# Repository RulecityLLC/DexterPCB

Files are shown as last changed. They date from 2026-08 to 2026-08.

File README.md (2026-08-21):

# DexterPCB
Contains all files needed to create/modify the Dexter custom PCB.

Dexter is a hardware replacement for laserdisc players used in arcade games such as Dragon's Lair.

Dexter is a two board solution: a larger custom PCB that sits on the bottom and a smaller Raspberry Pi v2 the sits on the top.  This repo contains the Eagle files and Bill of Materials spreadsheet to create/modify the custom PCB that sits on the bottom.

The Dexter custom PCB contains two microcontrollers.  The source code for these microcontroller is at https://github.com/RulecityLLC/DexterFirmware .

# PCB
I created this PCB with Eagle v6.  It should work with KiCad's EAGLE importer though I have not tested it.

# Bill of Materials
I included the actual spreadsheet I use when ordering parts for this PCB and assembling this PCB.

# Support
If you need help having PCBs made from the source files or with any other aspect of this repository, I offer commercial support: https://www.daphne-emu.com:9443/mediawiki/index.php/CommercialSupport

--Matt Ownby

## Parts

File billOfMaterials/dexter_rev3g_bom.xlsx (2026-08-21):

Quantity | Reference | Package | Manufacturer | Mfg # | Distributor | Dist # | Note | Best Price
SURFACE MOUNT
22 | C1-C4,C7-C10,C12-C13,C16-C24,C25-C27 | 1206 | Samsung | CL31B104JBCNNNC | Digi-Key | 1276-1165-1-ND | 0.1uF
4 | C5,C6,C14-C15 | 1206 | Kemet | C1206C200J5GACTU | Digi-Key | 399-1196-1-ND | 20pF (for both 16 MHz and 18.432 MHz crystals)
1 | IC1 | TQFP44 | Atmel | ATMEGA644PA-AU | Digi-Key | ATMEGA644PA-AU-ND | microcontroller
2 | IC2,IC4 | SO18 | Maxim | MAX222CWN+ | Digi-Key | MAX222CWN+-ND | serial drivers
1 | IC3 | 8-SOIC | TI | LM1881MX/NOPB | Digi-Key | LM1881MX/NOPBCT-ND | video sync separator (Digikey says discontinued!)
1 | IC5 | TSSOP24 | STP | STP16CP05TTR | Digi-Key | 497-5744-1-ND | LED driver
1 | IC6 | TSSOP20 | Texas Instruments | SN74LS244DBR | Digi-Key | 296-26509-1-ND | octal tri-state buffer
1 | IC7 | TSSOP5 | NXP | 74AHCT1G32GW,125 | Digi-Key | 568-4464-1-ND | OR gate 2-input. TI alternative: 296-4713-1-ND | newark for TI alternate
1 | IC8 | 4-SOP | IXYS Integrated Circuits Division | CPC1008NTR | Digi-Key | CLA216CT-ND | Solid state relay
1 | IC9 | TSSOP24 | Texas Instruments | SN74CBTD3384PWR | Digi-Key | 296-1173-1-ND | 5V <-> 3.3V I/O
1 | IC10 | TSSOP6 | Texas Instruments | SN74LVC1G332DCKR | Digi-Key | 296-15943-1-ND | 3-input OR gate (high level is > 3.5V which is ok since AVR is sourcing all inputs)
1 | IC11 | TSSOP14 | Diodes Inc. | 74HCT126T14-13 | Digi-Key | 74HCT126T14-13DICT-ND | tri-state buffer
14 | LED2,LED3,LED6,LED7,LED8,LED10,LED11,LED13,LED14,LED15,LED16,LED17,LED18,LED19 | 1206 | Kingbright Company LLC | APT3216SGC | Digi-Key | 754-1141-1-ND | All LEDs
3 | R1,R23,R25 | 1206 | Panasonic | ERJ-8ENF6803V | Digi-Key | P680KFCT-ND | R680k
2 | R2,R22 | 1206 | Panasonic | ERJ-8ENF3300V | Digi-Key | P330FCT-ND | R330
5 | R3,R7,R14,R19,R21 | 1206 | Panasonic | ERJ-8ENF1501V | Digi-Key | P1.50KFCT-ND | R1500
7 | R4,R5,R10,R11,R13,R16,R24 | 1206 | Panasonic | ERJ-8ENF1001V | Digi-Key | P1.00KFCT-ND | R1k
3 | R6,R9,R15 | 1206 | Panasonic | ERJ-8ENF75R0V | Digi-Key | P75.0FCT-ND | R75
4 | R8,R12,R26,R27 | 1206 | Panasonic | ERJ-8ENF4701V | Digi-Key | P4.70KFCT-ND | R4.7k
3 | R17,R18,R20 | 1206 | Panasonic | ERJ-8ENF7500V | Digi-Key | P750FCT-ND | R750
1 | U1 | UMAX (SMD) | Maxim | MAX4313EUA+ | Digi-Key | MAX4313EUA+-ND | video MUX
1 | U2 | TQFP32 | Atmel | ATMEGA328P-AU | Digi-Key | ATMEGA328P-AU-ND | ATMEGA328P
1 | Y1 | CRYSTAL-CSM-3X (SMD) | ECS Inc | ECS-184-20-3X-TR | Digi-Key | XC1777CT-ND | 18.432 MHz
1 | Y2 | CRYSTAL-CSM-3X (SMD) | ECS Inc | ECS-160-20-3X-TR | Digi-Key | XC1776CT-ND | 16 MHz
2 | Z1,Z2 | SOT-23 (SMD) | Micro Commercial Co | BAT54S-TP | Digi-Key | BAT54STPMSCT-ND | BAT54S
THROUGH-HOLE
3 | S2-S4 | TACTILE-PTH | Omron | B3F-1020 | Digi-Key | SW402-ND | push button
1 | X1 | DB25 (PTH) | TE Connectivity | 5745783-4 | Digi-Key | A32077-ND | DB25 | Mouser/Newark ($3.22/ea for 100+)
1 | X2 | CENTRONICS24 (PTH) | Norcomp Inc | 112-024-213R001 | Digi-Key | 1024RFA-ND | CENTRONICS 24 (warning, stock is low, we may need to find different supplier) | DO NOT INSTALL FASTENER THINGIES, Star Rider connector isn't compatible with them
1 | JP7 | 2x13 (PTH) | TE Connectivity | 5103308-6 | Digi-Key | A33167-ND | Raspberry Pi header
2 | JP16,JP17 | 1X2 (keyed, PTH) | Molex | 22232021 | Digi-Key | WM4200-ND | 1x2 keyed header (5V/GND)
1 | IR1 | VISHAY | Vishay | TSOP2438 | Digi-Key | TSOP2438-ND | Infrared receiver (see also TSOP32438-ND which looks to be compatible and newer)
2 | J1,J8 | 2X3 (PTH) | Molex | 901310123 | Digi-Key | WM8121-ND | 2x3 pin header for ISP program
1 | J2 | POWER_JACK_PTH | CUI | PJ-002A | Digi-Key | CP-002A-ND | power jack
1 | J3 | BNCPTH | TE Connectivity | 1-1478031-0 | Digi-Key | ACX1971-ND | 75 ohm BNC connector (A97559-ND is older obsolete part)
1 | J5 | 3.5mm stereo with tip | CUI | SJ1-3554NG | Digi-Key | CP1-3554NG-ND | 3.5mm stereo jack with tip switch (PR-8210 jack) [alternate part CP1-3544N-ND]
1 | J4 | 3.5mm 4 terminals (PTH) | CUI | SJ-43514 | Digi-Key | CP-43514-ND | 3.5mm A/V jack (4 terminals) [digikey was out of stock for these but then got 20k in so be careful]
1 | C11 | CPOL-RADIAL (PTH) | Panasonic | EEU-FC1A471 | Digi-Key | P10221-ND | 470uF/10V (alt UPW1A471MPD)
1 | F1 | PTCPTH | Littelfuse, Inc | 72R025XU | Digi-Key | F3193-ND | Resettable fuse PTC. 250mA Newer replacement: RXEF025HF-ND
1 | AUD_LEFT | RCA-SWITCHCRAFT-4X (PTH) | Switchcraft | PJRAN1X1U01X | Digi-Key | PJRAN1X1U01X-ND | RCA port (black)
1 | AUD_RIGHT | RCA-SWITCHCRAFT-4X (PTH) | Switchcraft | PJRAN1X1U03X | Digi-Key | PJRAN1X1U03X-ND | RCA port (red)

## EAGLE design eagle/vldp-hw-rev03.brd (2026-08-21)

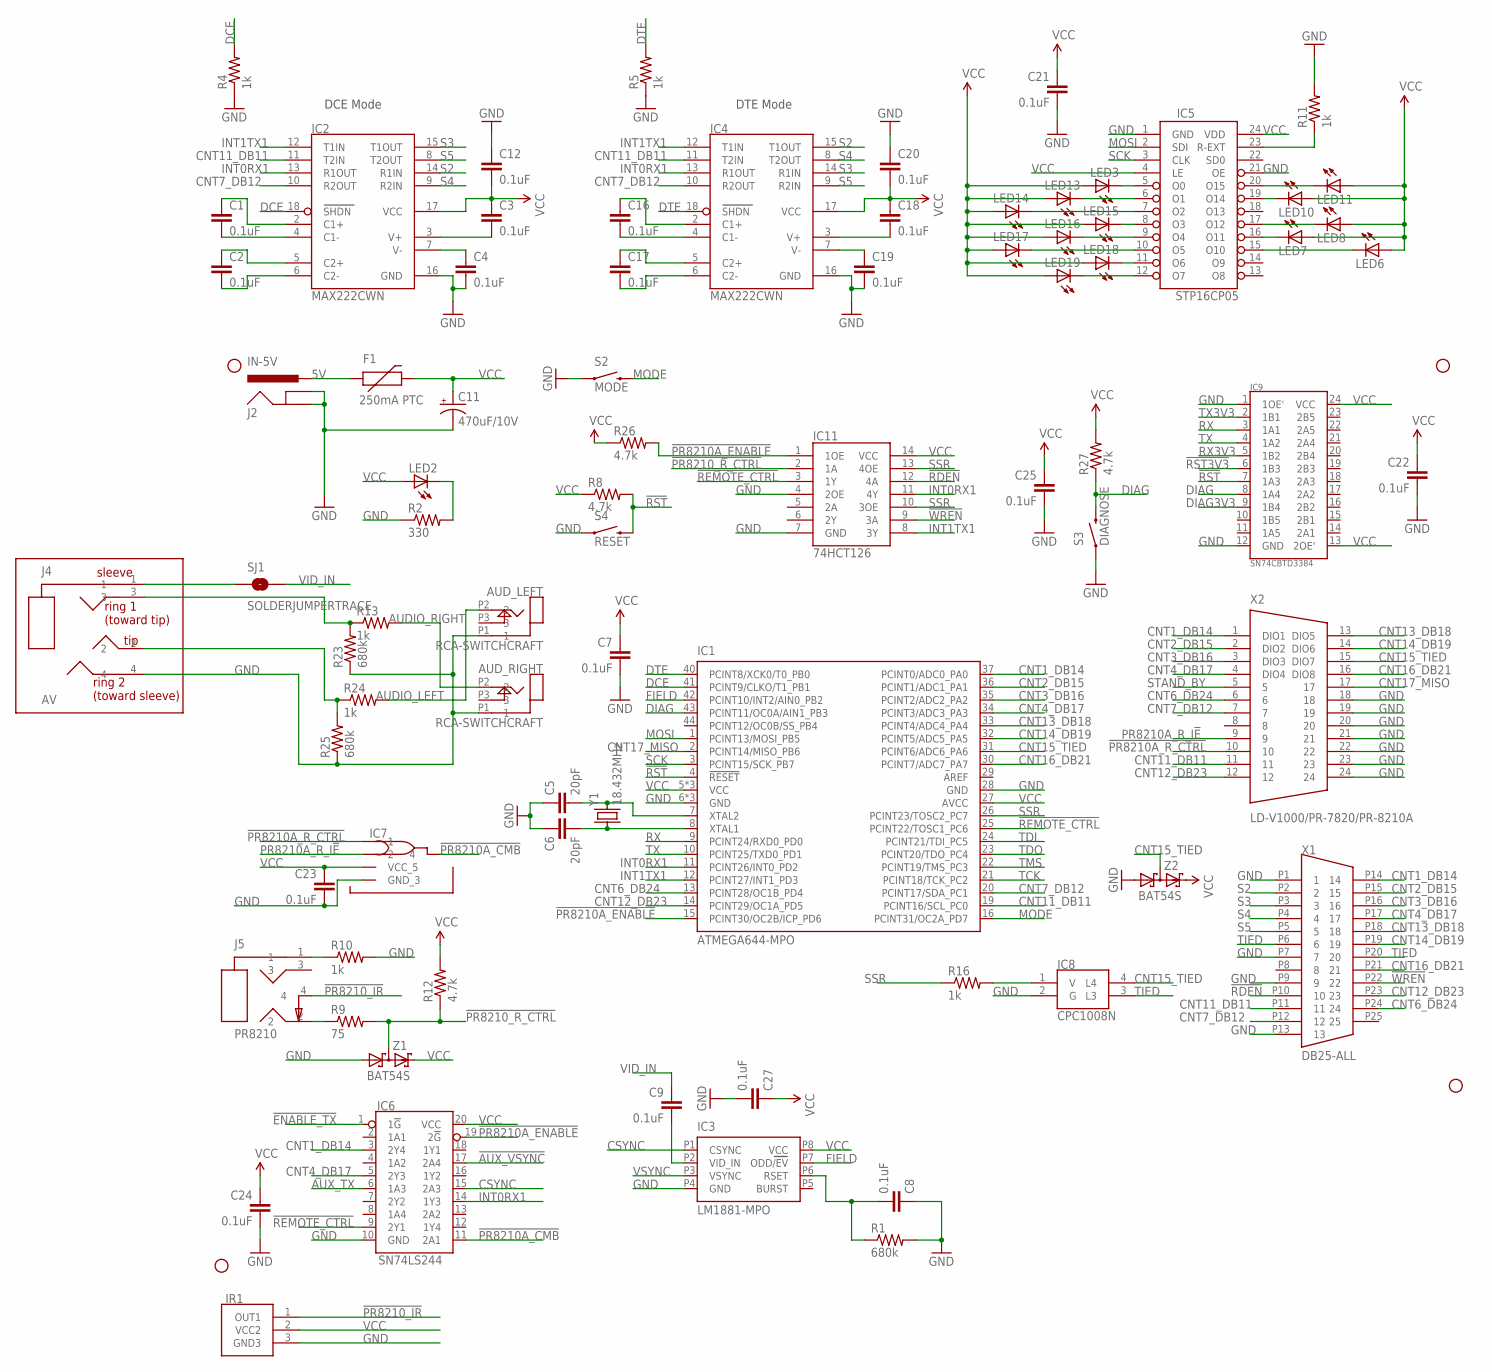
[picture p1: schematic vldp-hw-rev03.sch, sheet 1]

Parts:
AUD_LEFT: RCA-SWITCHCRAFT; RCA-SWITCHCRAFT-4X
AUD_RIGHT: RCA-SWITCHCRAFT; RCA-SWITCHCRAFT-4X
C1, C2, C3, C4, C7, C8, C9, C12, C16, C17, C18, C19, C20, C21, C22, C23, C24, C25, C27: 0.1uF; 1206
C5, C6: 20pF; 1206
C11: 470uF/10V; CPOL-RADIAL-10UF-25V
F1: 250mA PTC; PTC
IC1: ATMEGA644-MPO; TQFP44
IC2, IC4: MAX222CWN; SO18
IC3: LM1881-MPO; LM1881M
IC5: STP16CP05; TSSOP24
IC6: SN74LS244; TSSOP20-MPO
IC7: PR8210A_RMT; TSSOP5
IC8: CPC1008N
IC9: SN74CBTD3384; TSSOP24
IC11: 74HCT126; TSSOP14-MPO
IR1: TSOP2438; VISHAY
J2: IN-5V; POWER_JACK_PTH
J4: AV; 3.5MM-SJ-43514
J5: PR8210; 3.5MM-SJ1-3554NG
JP1, JP2, JP3, JP4: STAND-OFF
LED2, LED3, LED6, LED7, LED8, LED10, LED11, LED13, LED14, LED15, LED16, LED17, LED18, LED19: LED1206; LED-1206
R1, R23, R25: 680k; 1206
R2: 330; 1206
R4, R5, R10, R11, R13, R16, R24: 1k; 1206
R8, R12, R26, R27: 4.7k; 1206
R9: 75; 1206
S2: MODE; TACTILE-PTH
S3: DIAGNOSE; TACTILE-PTH
S4: RESET; TACTILE-PTH
SJ1: SOLDERJUMPERTRACE; SJ_2S-TRACE
X1: DB25-ALL; A32077-ND
X2: LD-V1000/PR-7820/PR-8210A; 112-YYY-213R001
Y1: 18.432MHz; CRYSTAL-CSM-3X
Z1, Z2: BAT54S; SOT23

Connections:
5V: F1.P$1 (1), J2.PWR; also elsewhere on the board
!AUX_VSYNC: IC6.17 (2A4); also elsewhere on the board
!ENABLE_TX: IC6.1 (1!G); also elsewhere on the board
!PR8210A_CMB: IC6.11 (2A1), IC7.P$4 (4)
!PR8210A_ENABLE: IC1.15 (PCINT30/OC2B/ICP_PD6), IC6.19 (2!G), IC11.1 (1OE), R26.2
!PR8210A_R_CTRL: IC7.P$1 (1), X2.10
!PR8210_IR: IR1.1 (OUT1), J5.4
!PR8210_R_CTRL: IC11.2 (1A), R9.2, R12.1, Z1.3 (C1A2)
!RDEN: IC11.12 (4A), X1.P10 (10)
!REMOTE_CTRL: IC1.25 (PCINT22/TOSC1_PC6), IC6.9 (2Y1), IC11.3 (1Y)
!RST: IC1.4 (!RESET), IC9.7 (1A3), R8.2, S4.3 (2); also elsewhere on the board
!RST3V3: IC9.6 (1B3); also elsewhere on the board
!WREN: IC11.9 (3A), X1.P22 (22)
AUDIO_LEFT: AUD_LEFT.P2 (2), R24.2; also elsewhere on the board
AUDIO_RIGHT: AUD_RIGHT.P2 (2), R13.2; also elsewhere on the board
AUX_TX: IC6.6 (1A3); also elsewhere on the board
CNT1_DB14: IC1.37 (PCINT0/ADC0_PA0), IC6.3 (2Y4), X1.P14 (14), X2.1 (DIO1)
CNT2_DB15: IC1.36 (PCINT1/ADC1_PA1), X1.P15 (15), X2.2 (DIO2)
CNT3_DB16: IC1.35 (PCINT2/ADC2_PA2), X1.P16 (16), X2.3 (DIO3)
CNT4_DB17: IC1.34 (PCINT3/ADC3_PA3), IC6.5 (2Y3), X1.P17 (17), X2.4 (DIO4)
CNT6_DB24: IC1.13 (PCINT28/OC1B_PD4), X1.P24 (24), X2.6; also elsewhere on the board
CNT7_DB12: IC1.20 (PCINT17/SDA_PC1), IC2.10 (R2OUT), IC4.10 (R2OUT), X1.P12 (12), X2.7
CNT11_DB11: IC1.19 (PCINT16/SCL_PC0), IC2.11 (T2IN), IC4.11 (T2IN), X1.P11 (11), X2.11; also elsewhere on the board
CNT12_DB23: IC1.14 (PCINT29/OC1A_PD5), X1.P23 (23), X2.12; also elsewhere on the board
CNT13_DB18: IC1.33 (PCINT4/ADC4_PA4), X1.P18 (18), X2.13 (DIO5)
CNT14_DB19: IC1.32 (PCINT5/ADC5_PA5), X1.P19 (19), X2.14 (DIO6)
CNT15_TIED: IC1.31 (PCINT6/ADC6_PA6), IC8.4 (L4), X2.15 (DIO7), Z2.3 (C1A2)
CNT16_DB21: IC1.30 (PCINT7/ADC7_PA7), X1.P21 (21), X2.16 (DIO8)
CNT17_MISO: IC1.2 (PCINT14/MISO_PB6), X2.17; also elsewhere on the board
CSYNC: IC3.P1 (CSYNC), IC6.15 (2A3); also elsewhere on the board
DCE: IC1.41 (PCINT9/CLKO/T1_PB1), IC2.18 (SHDN), R4.2; also elsewhere on the board
DIAG: IC1.43 (PCINT11/OC0A/AIN1_PB3), IC9.8 (1A4), R27.1, S3.3 (2); also elsewhere on the board
DIAG3V3: IC9.9 (1B4); also elsewhere on the board
DTE: IC1.40 (PCINT8/XCK0/T0_PB0), IC4.18 (SHDN), R5.2; also elsewhere on the board
FIELD: IC1.42 (PCINT10/INT2/AIN0_PB2), IC3.P7 (ODD/EV); also elsewhere on the board
GND: AUD_LEFT.P1 (1), AUD_RIGHT.P1 (1), C4.2, C5.1, C6.1, C7.2, C8.1, C11.2 (-), C12.1, C19.2, C20.1, C21.2, C22.2, C23.2, C24.2, C25.2, C27.2, IC1.6 (GND), IC1.18 (GND), IC1.28 (GND), IC1.39 (GND), IC2.16 (GND), IC3.P4 (GND), IC4.16 (GND), IC5.1 (GND), IC5.21 (OE), IC6.10 (GND), IC7.P$3 (GND_3), IC8.2 (G), IC9.1 (1OE'), IC9.12 (GND), IC11.4 (2OE), IC11.7 (GND), IR1.3 (GND3), J2.GND, J2.GNDBREAK, J4.4, R1.2, R2.1, R4.1, R5.1, R10.2, R11.2, R23.1, R25.1, S2.1, S3.1, S4.1, X1.P1 (1), X1.P7 (7), X1.P9 (9), X1.P13 (13), X2.18, X2.19, X2.20, X2.21, X2.22, X2.23, X2.24, Z1.1 (A1), Z2.1 (A1); also elsewhere on the board
INT0RX1: IC1.11 (PCINT26/INT0_PD2), IC2.13 (R1OUT), IC4.13 (R1OUT), IC6.14 (1Y3), IC11.11 (4Y); also elsewhere on the board
INT1TX1: IC1.12 (PCINT27/INT1_PD3), IC2.12 (T1IN), IC4.12 (T1IN), IC11.8 (3Y); also elsewhere on the board
MODE: IC1.16 (PCINT31/OC2A_PD7), S2.3 (2)
MOSI: IC1.1 (PCINT13/MOSI_PB5), IC5.2 (SDI); also elsewhere on the board
unnamed: C2.1, IC2.5 (C2+)
unnamed: C5.2, IC1.7 (XTAL2), Y1.P$2
unnamed: C6.2, IC1.8 (XTAL1), Y1.P$1
unnamed: C1.2, IC2.4 (C1-)
unnamed: C1.1, IC2.2 (C1+)
unnamed: IC8.1 (V), R16.2
unnamed: C2.2, IC2.6 (C2-)
unnamed: C16.2, IC4.4 (C1-)
unnamed: J5.1, R10.1
unnamed: C8.2, IC3.P6 (RSET), R1.1
unnamed: C9.2, IC3.P2 (VID_IN)
unnamed: LED2.C, R2.2
unnamed: J4.1, SJ1.1
unnamed: J4.2, R24.1, R25.2
unnamed: IC5.5 (O0), LED3.C
unnamed: IC5.6 (O1), LED13.C
unnamed: IC5.7 (O2), LED14.C
unnamed: IC5.8 (O3), LED15.C
unnamed: C16.1, IC4.2 (C1+)
unnamed: C17.1, IC4.5 (C2+)
unnamed: C17.2, IC4.6 (C2-)
unnamed: IC5.9 (O4), LED16.C
unnamed: IC5.10 (O5), LED17.C
unnamed: IC5.11 (O6), LED18.C
unnamed: IC5.12 (O7), LED19.C
unnamed: J4.3, R13.1, R23.2
unnamed: IC5.15 (O10), LED6.C
unnamed: IC5.16 (O11), LED7.C
unnamed: IC5.17 (O12), LED8.C
unnamed: IC5.19 (O14), LED10.C
unnamed: IC5.20 (O15), LED11.C
unnamed: IC5.23 (R-EXT), R11.1
PR8210A_R_I!E: IC7.P$2 (2), X2.9
PR8210_TIP: J5.2, R9.1
RX: IC1.9 (PCINT24/RXD0_PD0), IC9.3 (1A1); also elsewhere on the board
RX3V3: IC9.5 (1B2); also elsewhere on the board
S2: IC2.14 (R1IN), IC4.15 (T1OUT), X1.P2 (2)
S3: IC2.15 (T1OUT), IC4.14 (R1IN), X1.P3 (3)
S4: IC2.9 (R2IN), IC4.8 (T2OUT), X1.P4 (4)
S5: IC2.8 (T2OUT), IC4.9 (R2IN), X1.P5 (5)
SCK: IC1.3 (PCINT15/SCK_PB7), IC5.3 (CLK); also elsewhere on the board
SSR: IC1.26 (PCINT23/TOSC2_PC7), IC11.10 (3OE), IC11.13 (4OE), R16.1; also elsewhere on the board
STAND_BY: X2.5; also elsewhere on the board
TCK: IC1.21 (PCINT18/TCK_PC2); also elsewhere on the board
TDI: IC1.24 (PCINT21/TDI_PC5); also elsewhere on the board
TDO: IC1.23 (PCINT20/TDO_PC4); also elsewhere on the board
TIED: IC8.3 (L3), X1.P6 (6), X1.P20 (20)
TMS: IC1.22 (PCINT19/TMS_PC3); also elsewhere on the board
TX: IC1.10 (PCINT25/TXD0_PD1), IC9.4 (1A2); also elsewhere on the board
TX3V3: IC9.2 (1B1); also elsewhere on the board
V+1: C3.2, IC2.3 (V+)
V+2: C18.2, IC4.3 (V+)
V-1: C4.1, IC2.7 (V-)
V-2: C19.1, IC4.7 (V-)
VCC: C3.1, C7.1, C11.1 (+), C12.2, C18.1, C20.2, C21.1, C22.1, C23.1, C24.1, C25.1, C27.1, F1.P$2 (2), IC1.5 (VCC), IC1.17 (VCC), IC1.27 (AVCC), IC1.38 (VCC), IC2.17 (VCC), IC3.P8 (VCC), IC4.17 (VCC), IC5.4 (LE), IC5.24 (VDD), IC6.20 (VCC), IC7.P$5 (VCC_5), IC9.13 (2OE'), IC9.24 (VCC), IC11.14 (VCC), IR1.2 (VCC2), LED2.A, LED3.A, LED6.A, LED7.A, LED8.A, LED10.A, LED11.A, LED13.A, LED14.A, LED15.A, LED16.A, LED17.A, LED18.A, LED19.A, R8.1, R12.2, R26.1, R27.2, Z1.2 (C2), Z2.2 (C2); also elsewhere on the board
VID_IN: C9.1, SJ1.2; also elsewhere on the board
VSYNC: IC3.P3 (VSYNC); also elsewhere on the board

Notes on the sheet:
DCE Mode
DTE Mode

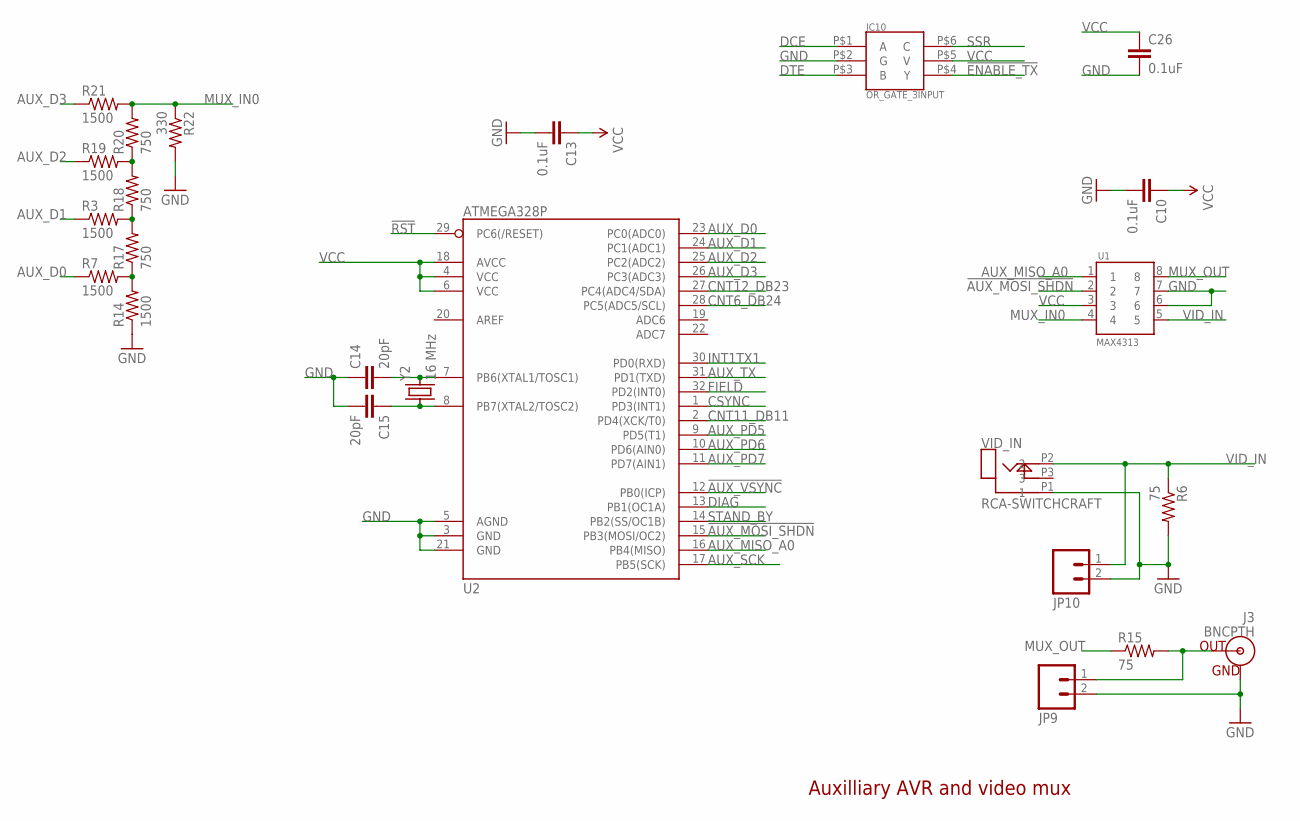
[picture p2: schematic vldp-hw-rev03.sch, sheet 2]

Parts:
C10, C13, C26: 0.1uF; 1206
C14, C15: 20pF; 1206
IC10: OR_GATE_3INPUT; TSSOP6-DCK
J3: BNCPTH; BNC
JP9, JP10: M02PTH; 1X02
R3, R7, R14, R19, R21: 1500; 1206
R6, R15: 75; 1206
R17, R18, R20: 750; 1206
R22: 330; 1206
U1: MAX4313; MAXIM-UMAX-LONGPADS
U2: ATMEGA328P; TQFP32-LONGPADS
VID_IN: RCA-SWITCHCRAFT; RCA-SWITCHCRAFT-4X
Y2: 16 MHz; CRYSTAL-CSM-3X

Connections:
!AUX_MOSI_SHDN: U1.2, U2.15 (PB3(MOSI/OC2)); also elsewhere on the board
!AUX_VSYNC: U2.12 (PB0(ICP)); also elsewhere on the board
!ENABLE_TX: IC10.P$4 (Y); also elsewhere on the board
!RST: U2.29 (PC6(/RESET)); also elsewhere on the board
AUX_D0: R7.1, U2.23 (PC0(ADC0))
AUX_D1: R3.1, U2.24 (PC1(ADC1))
AUX_D2: R19.1, U2.25 (PC2(ADC2))
AUX_D3: R21.1, U2.26 (PC3(ADC3))
AUX_MISO_A0: U1.1, U2.16 (PB4(MISO)); also elsewhere on the board
AUX_PD5: U2.9 (PD5(T1)); also elsewhere on the board
AUX_PD6: U2.10 (PD6(AIN0)); also elsewhere on the board
AUX_PD7: U2.11 (PD7(AIN1)); also elsewhere on the board
AUX_SCK: U2.17 (PB5(SCK)); also elsewhere on the board
AUX_TX: U2.31 (PD1(TXD)); also elsewhere on the board
CNT6_DB24: U2.28 (PC5(ADC5/SCL)); also elsewhere on the board
CNT11_DB11: U2.2 (PD4(XCK/T0)); also elsewhere on the board
CNT12_DB23: U2.27 (PC4(ADC4/SDA)); also elsewhere on the board
CSYNC: U2.1 (PD3(INT1)); also elsewhere on the board
DCE: IC10.P$1 (A); also elsewhere on the board
DIAG: U2.13 (PB1(OC1A)); also elsewhere on the board
DTE: IC10.P$3 (B); also elsewhere on the board
FIELD: U2.32 (PD2(INT0)); also elsewhere on the board
GND: C10.2, C13.2, C14.1, C15.2, C26.2, IC10.P$2 (G), J3.GND, JP9.2, JP10.2, R6.2, R14.1, R22.2, U1.6, U1.7, U2.3 (GND), U2.5 (AGND), U2.21 (GND), VID_IN.P1 (1); also elsewhere on the board
INT1TX1: U2.30 (PD0(RXD)); also elsewhere on the board
MUX_IN0: R20.2, R21.2, R22.1, U1.4
MUX_OUT: R15.1, U1.8
unnamed: J3.S (OUT), JP9.1, R15.2
unnamed: R3.2, R17.2, R18.1
unnamed: R7.2, R14.2, R17.1
unnamed: R18.2, R19.2, R20.1
unnamed: C14.2, U2.7 (PB6(XTAL1/TOSC1)), Y2.P$2
unnamed: C15.1, U2.8 (PB7(XTAL2/TOSC2)), Y2.P$1
SSR: IC10.P$6 (C); also elsewhere on the board
STAND_BY: U2.14 (PB2(SS/OC1B)); also elsewhere on the board
VCC: C10.1, C13.1, C26.1, IC10.P$5 (V), U1.3, U2.4 (VCC), U2.6 (VCC), U2.18 (AVCC); also elsewhere on the board
VID_IN: JP10.1, R6.1, U1.5, VID_IN.P2 (2); also elsewhere on the board

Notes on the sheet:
Auxilliary AVR and video mux

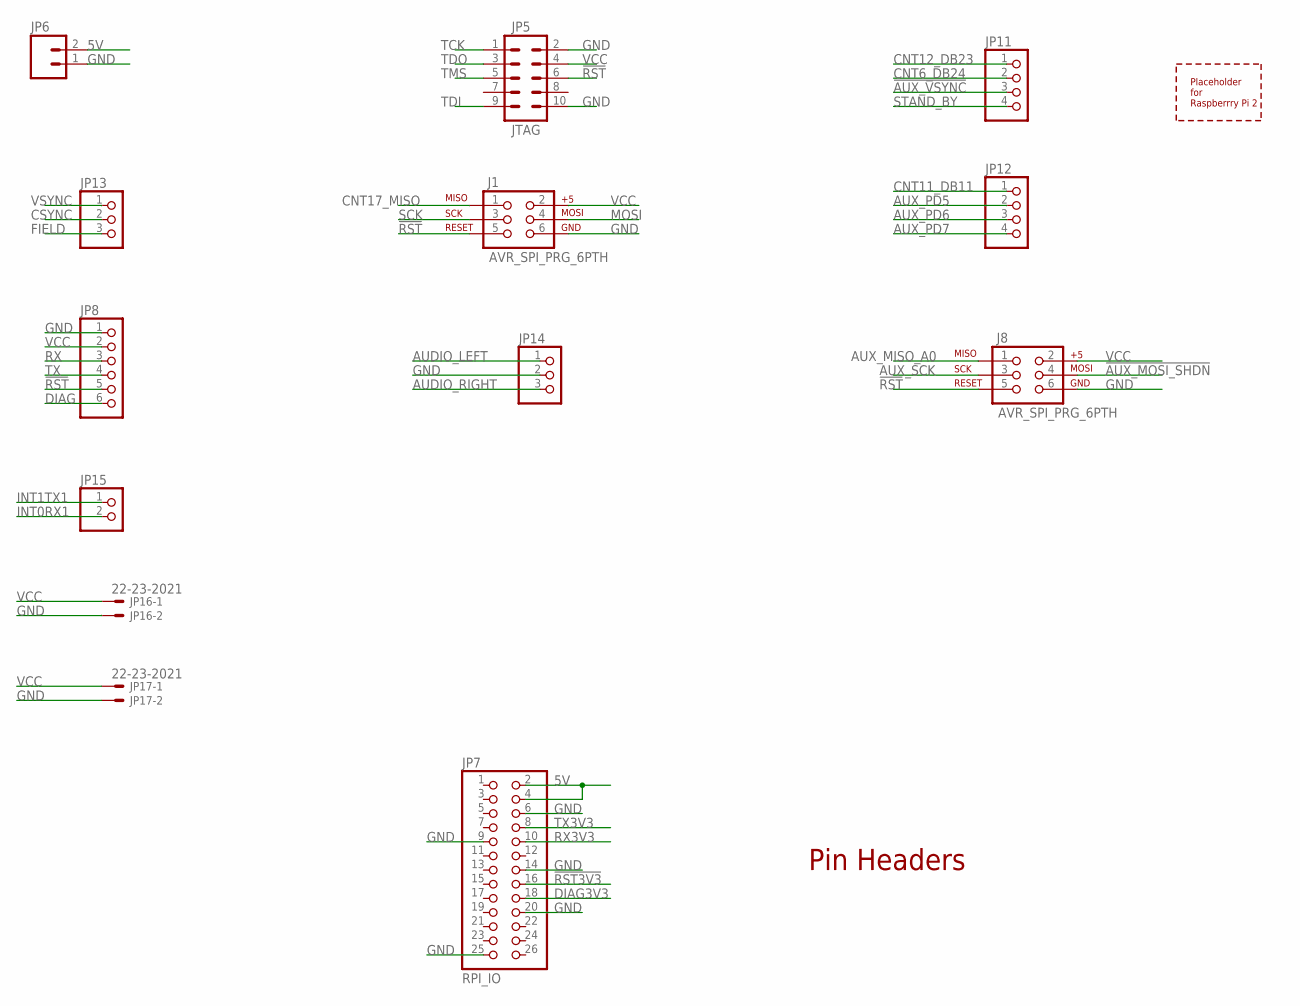
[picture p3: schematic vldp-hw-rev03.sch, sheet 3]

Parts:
J1, J8: AVR_SPI_PRG_6PTH; 2X3
JP5: JTAG; AVR_ICSP
JP6: M02PTH; 1X02
JP7: RPI_IO; 2X13
JP8: PINHD-1X6; 1X06
JP11, JP12: PINHD-1X4; 1X04
JP13, JP14: PINHD-1X3; 1X03
JP15: PINHD-1X2; 1X02
JP16, JP17: 22-23-2021
U$1: RASPBERRY_PI2_LAYOUT; RPI2

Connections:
5V: JP6.2, JP7.2, JP7.4; also elsewhere on the board
!AUX_MOSI_SHDN: J8.4; also elsewhere on the board
!AUX_VSYNC: JP11.3; also elsewhere on the board
!RST: J1.5, J8.5, JP5.6, JP8.5; also elsewhere on the board
!RST3V3: JP7.16; also elsewhere on the board
AUDIO_LEFT: JP14.1; also elsewhere on the board
AUDIO_RIGHT: JP14.3; also elsewhere on the board
AUX_MISO_A0: J8.1; also elsewhere on the board
AUX_PD5: JP12.2; also elsewhere on the board
AUX_PD6: JP12.3; also elsewhere on the board
AUX_PD7: JP12.4; also elsewhere on the board
AUX_SCK: J8.3; also elsewhere on the board
CNT6_DB24: JP11.2; also elsewhere on the board
CNT11_DB11: JP12.1; also elsewhere on the board
CNT12_DB23: JP11.1; also elsewhere on the board
CNT17_MISO: J1.1; also elsewhere on the board
CSYNC: JP13.2; also elsewhere on the board
DIAG: JP8.6; also elsewhere on the board
DIAG3V3: JP7.18; also elsewhere on the board
FIELD: JP13.3; also elsewhere on the board
GND: J1.6, J8.6, JP5.2, JP5.10, JP6.1, JP7.6, JP7.9, JP7.14, JP7.20, JP7.25, JP8.1, JP14.2, JP16.2, JP17.2; also elsewhere on the board
INT0RX1: JP15.2; also elsewhere on the board
INT1TX1: JP15.1; also elsewhere on the board
MOSI: J1.4; also elsewhere on the board
RX: JP8.3; also elsewhere on the board
RX3V3: JP7.10; also elsewhere on the board
SCK: J1.3; also elsewhere on the board
STAND_BY: JP11.4; also elsewhere on the board
TCK: JP5.1; also elsewhere on the board
TDI: JP5.9; also elsewhere on the board
TDO: JP5.3; also elsewhere on the board
TMS: JP5.5; also elsewhere on the board
TX: JP8.4; also elsewhere on the board
TX3V3: JP7.8; also elsewhere on the board
VCC: J1.2, J8.2, JP5.4, JP8.2, JP16.1, JP17.1; also elsewhere on the board
VSYNC: JP13.1; also elsewhere on the board

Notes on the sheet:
Pin Headers

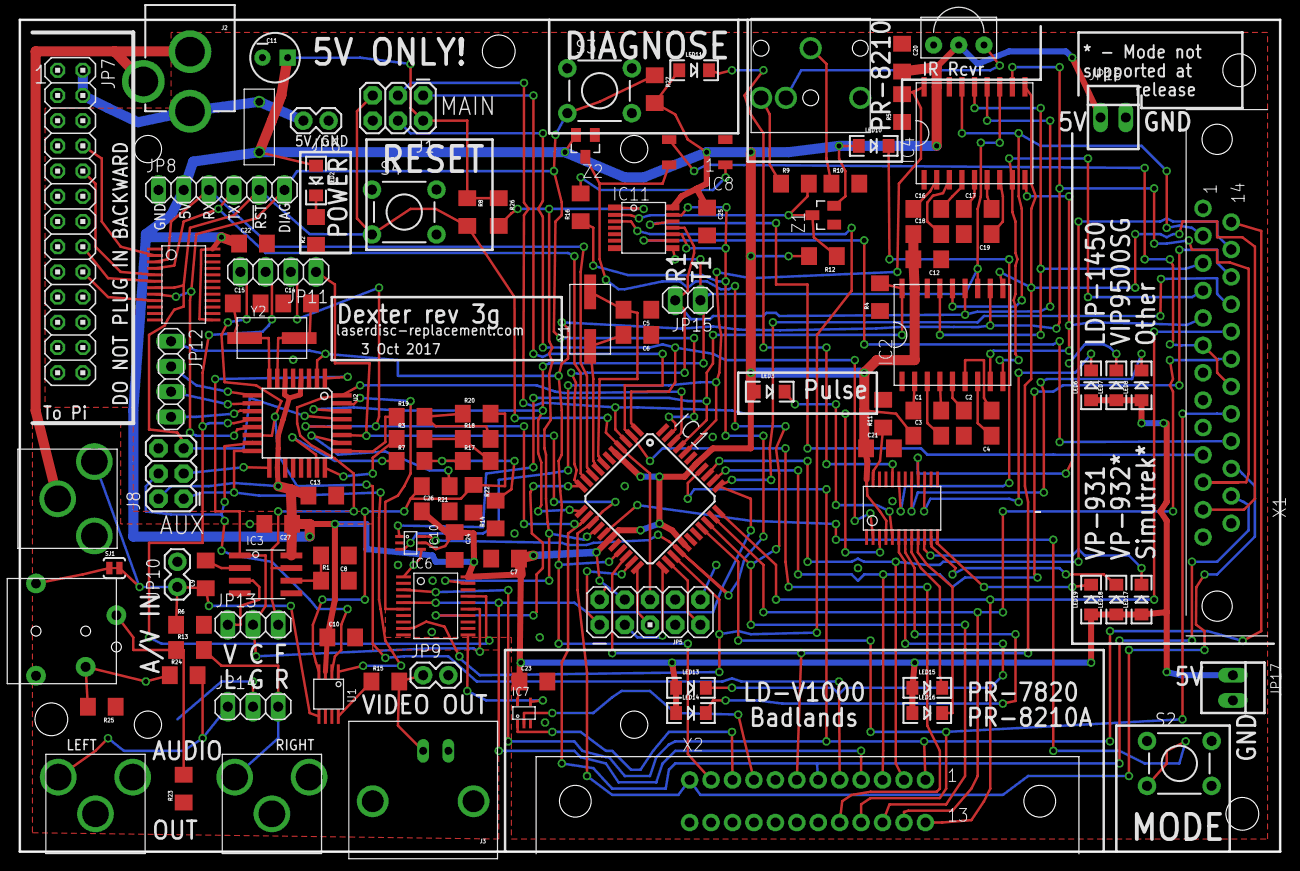
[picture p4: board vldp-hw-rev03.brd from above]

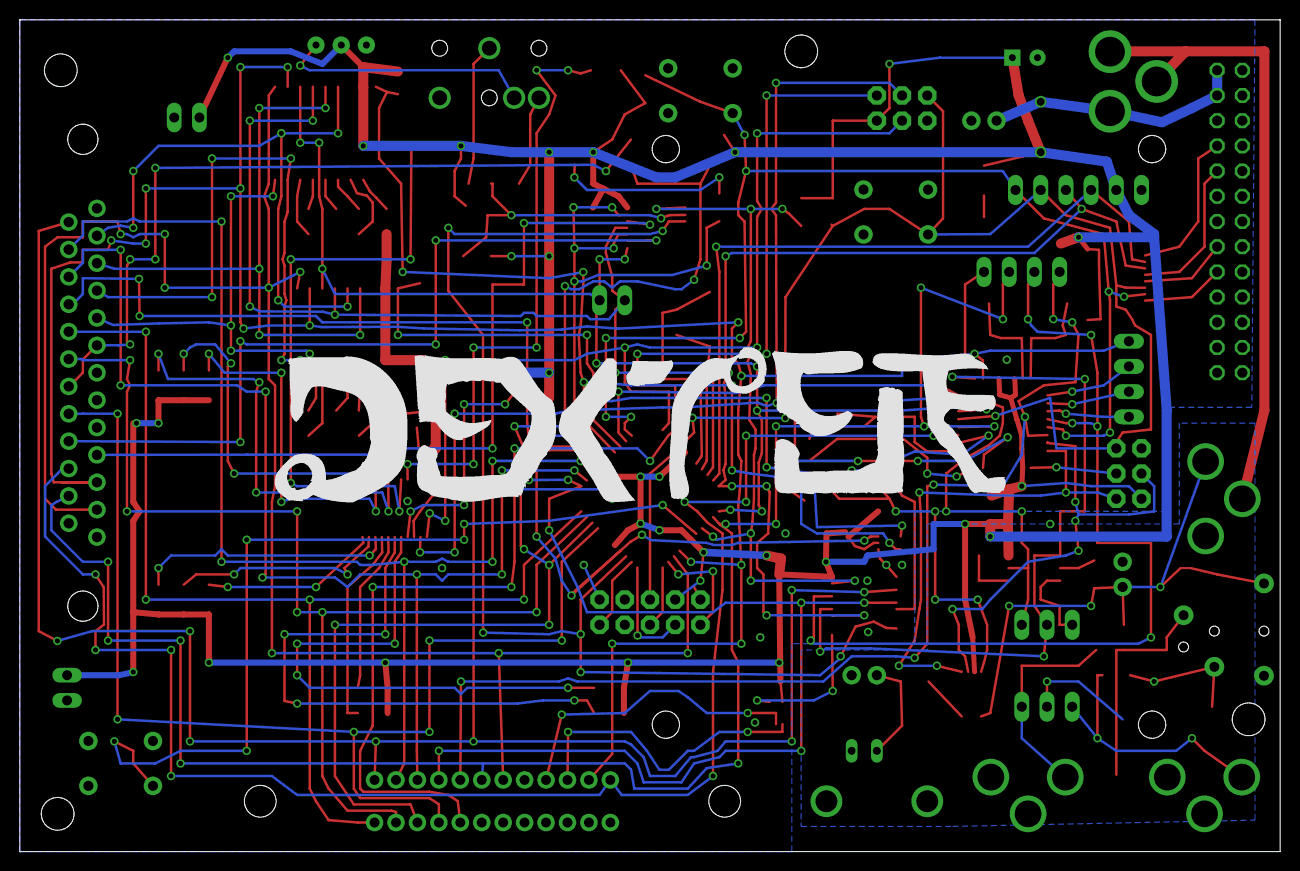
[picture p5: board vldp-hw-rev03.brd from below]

Board: 2 copper layers, 127.0 x 83.8 mm, 121 parts (3 on the bottom side), 115 nets.

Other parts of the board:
U$2: DEXTER_LOGO
